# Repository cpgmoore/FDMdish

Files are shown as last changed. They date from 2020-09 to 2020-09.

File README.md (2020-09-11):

# FDMdish
A 3D printable parabolic dish antenna, written in OpenSCAD, with examples rendered for immediate print.

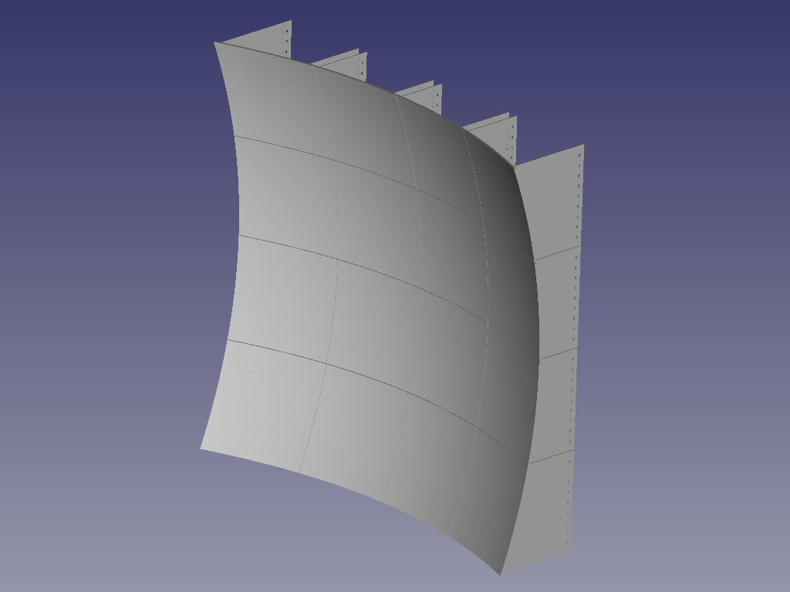
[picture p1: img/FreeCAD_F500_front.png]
|  |
|:-:|
| Included example render: 200mm tiles, 800x800mm dish size, focal distance 500mm |

FDMdish is a 3D printable, scalable parabolic reflector surface system suitable for use in a high gain radio antenna setup.
The parametric model is generated in OpenSCAD, STLs can be rendered/exported and used to generate tiles that can be 3D printed. The accompanying Cura slicer settings have been optimised for high speed printing, using a low volume of material for high paraboloid surface accuracy up to ~10Ghz (maybe 20GHz, requires testing).

The tiles are mounted to a frame of 2020 aluminium extrusion.
Use some currently unknown method to place the RF antenna feed at the focal point.

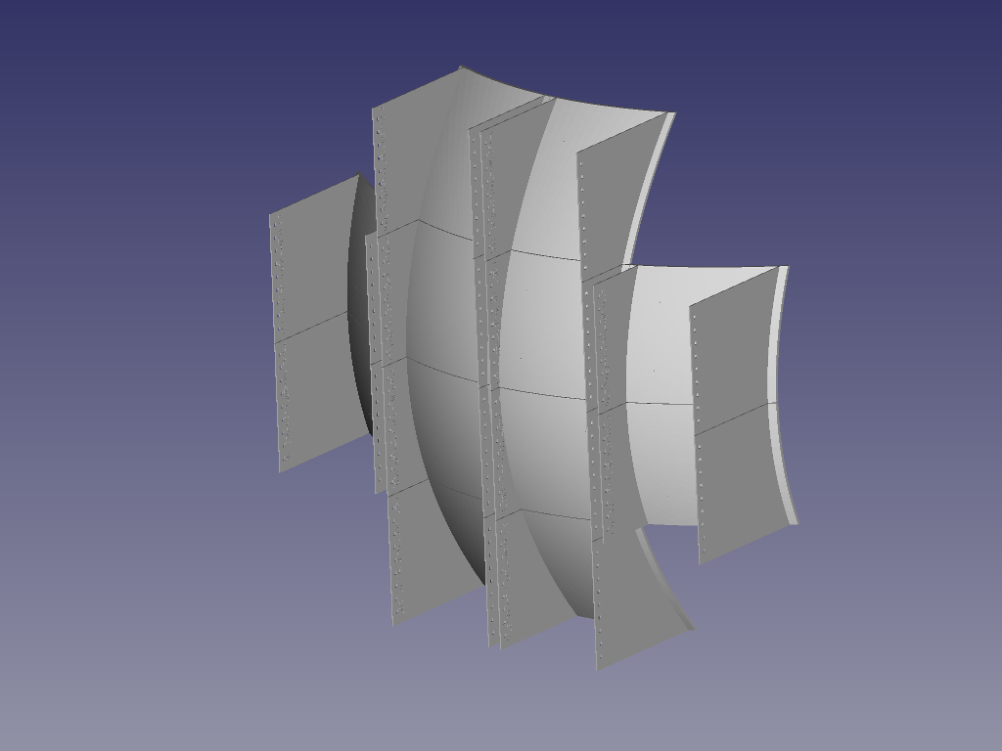
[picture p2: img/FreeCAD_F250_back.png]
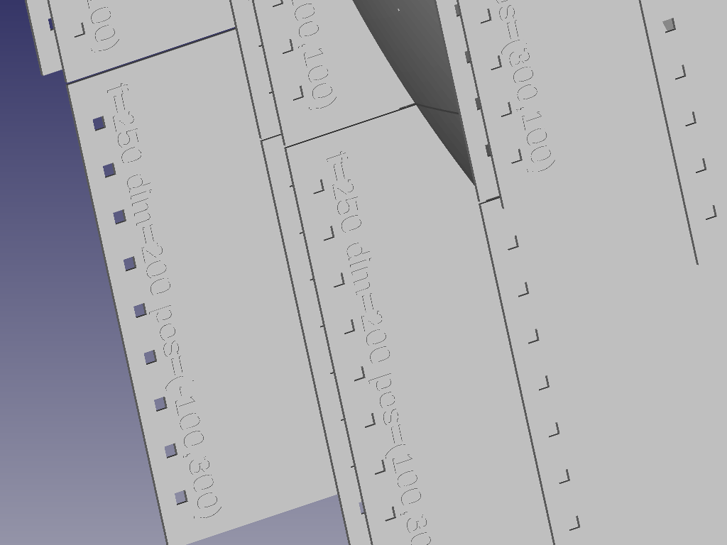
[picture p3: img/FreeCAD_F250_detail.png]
|   |   |
|:-:|:-:|
| Rear view, showing supports | Tiles are labeled |

## Ingredients:
* Ideal 3D printer: Artillery Sidewinder X1, with a 0.8mm nozzle for 1mm line width and 0.5mm layer height. Or equivalent machine
* A few KG of PLA filament, the slicer will tell you how much you need, white is less likely to melt in the sun than black
* Lengths of 2020 vslot extrusion or square hollow section, other widths are possible if you modify the OpenSCAD script
* Brackets to hold the 2020 extrusion in a sturdy frame (see images for examples)
* M5 (ideal), M4 or M3 fasteners and slot nuts
* Beers and patience
* Conductive tape, or conductive nickel spray paint for the reflector surface

## Method:
* Specific custom tiles can be generated by adjusting the parameters in the OpenSCAD script
* Whole dish assemblies can be batch rendered by modifying the parameters in the shell script, and running it (gen_dish.sh)
* The rendered STL files will be stored in the ./render folder
* Check the whole render job, but importing the STLs into a new FreeCAD project
* Load each of these files into your slicer of choice (an optimised profile for CURA and the Sidewinder X1 has been included for tips)
* The 3D printer and slicer should be set up for printing of dimensionally accurate functional components, otherwise there may be a few tight fits
* Print each tile out, trimming the brim
* Once printed, the tiles can be fastened to a grid of 2020 extrusion
* Get creative with ensuring the surface of the dish is electrically conductive, at least in the direction of polarisation, examples include:
 * Copper tape, spaced less than 1/10 wavelength apart
 * Conductive nickel spray paint
 * AluminIum foil and adhesive
 * Thin wire, taped down, ghetto pride

### Hints on SCAD tweaking:
* A high speed, thick layer height print process is unlikely to be tolerant of anything more than a 45deg overhang
 * So the on-axis diameter should be less than 4 times the focal length
* For a square dish at this critical limit, the corners are likely to exceed this requirement and may need to be discarded

### Hints on slicer settings:
* The SCAD model and slicer settings have been optimised for each other, the outcome may be less than ideal with a narrower nozzle
* The structural strength comes from the aluminium extrusion, these panels are designed to be rigid and low warp, but not load bearing
* 1 shell wall, fill of approximately 5-10% with a zigzag pattern seems to provide enough strength to prevent warping in the paraboloid as it cools
* Black gloss filament is good as a prototyping filament, because the quality of the surface can be quickly observed by looking for variations in the reflective sheen as the tile is rotated under a point source of illumination 
* printing with a brim is essential (these components are large, with a low bed contact area, and are otherwise likely to lift off the bed)

### Hints on printing:
* Approximate time per tile with the described setup: 2-3 hours

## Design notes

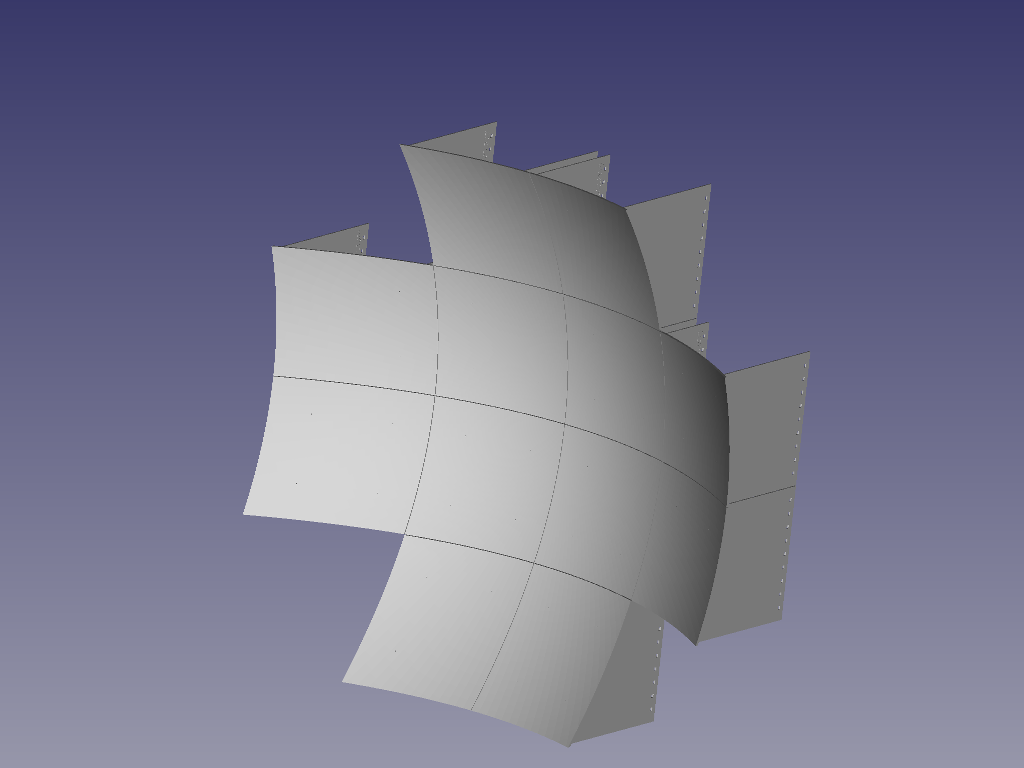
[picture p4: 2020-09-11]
img/FreeCAD_F250_front.png

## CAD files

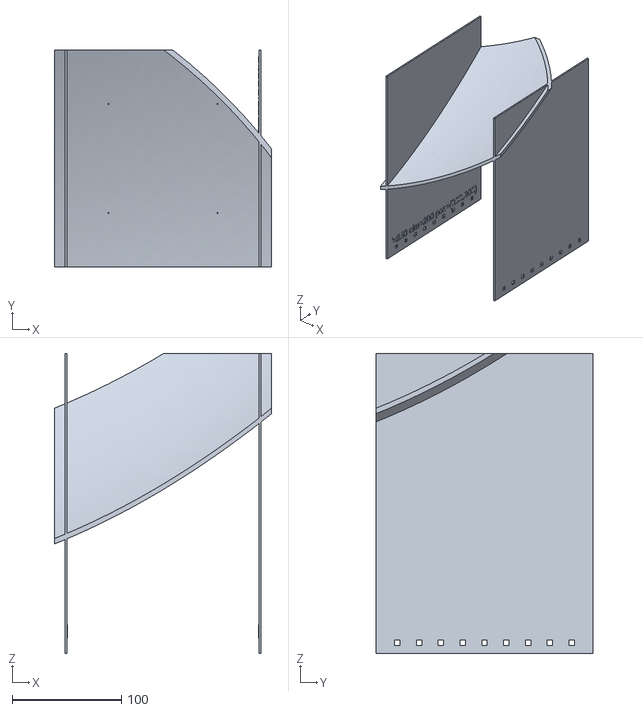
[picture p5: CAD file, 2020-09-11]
render/dish_F250_tile_200_+300_+300.stl
199.0 x 199.0 x 275.0

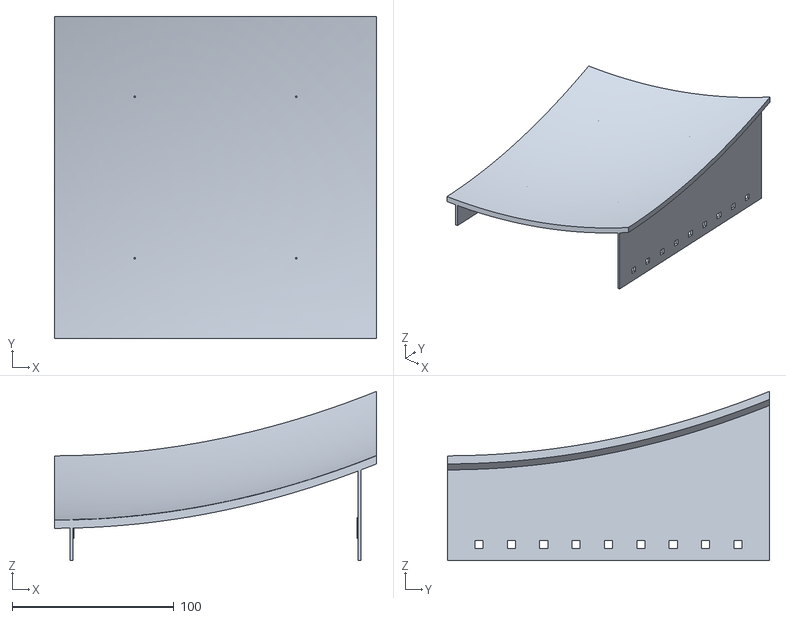
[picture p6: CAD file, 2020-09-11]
render/dish_F250_tile_200_+100_+100.stl
199.0 x 199.0 x 104.6

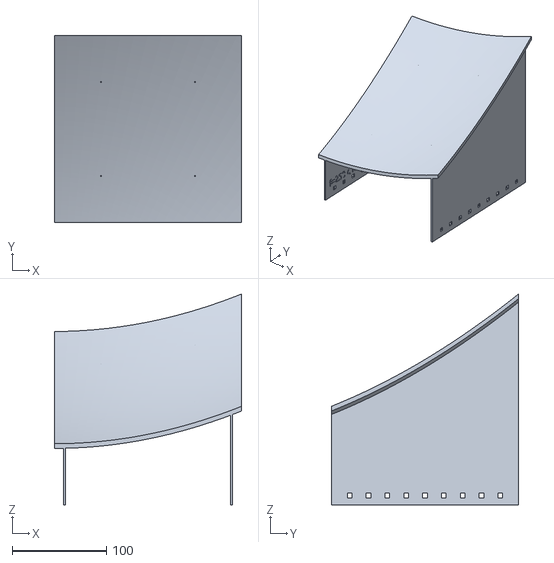
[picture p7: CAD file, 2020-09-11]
render/dish_F250_tile_200_+100_+300.stl
199.0 x 199.0 x 224.5

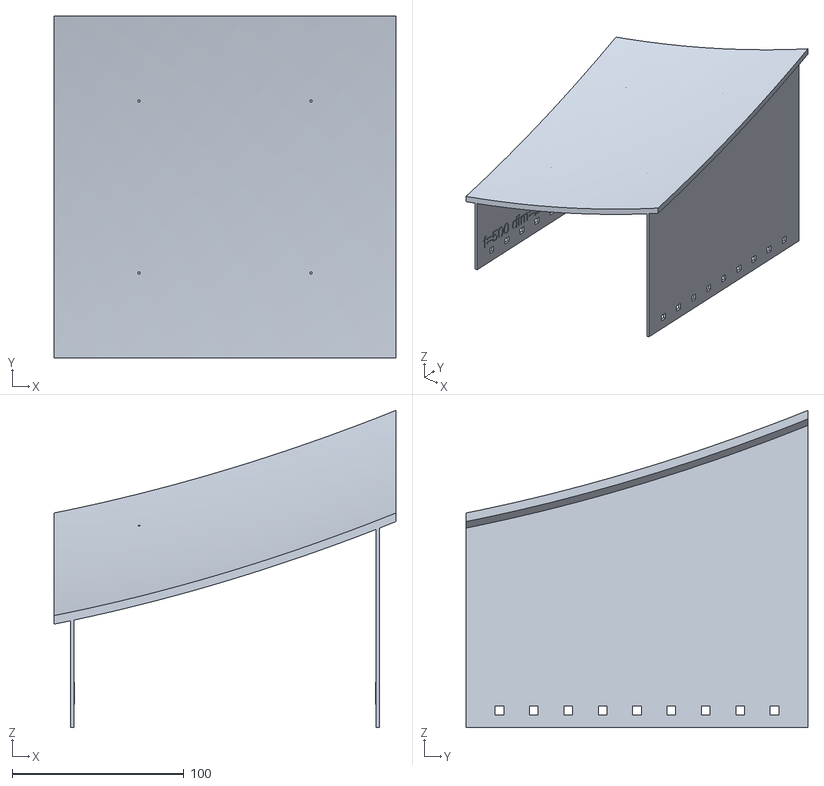
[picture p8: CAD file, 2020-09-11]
render/dish_F500_tile_200_+300_+300.stl
199.0 x 199.0 x 184.7

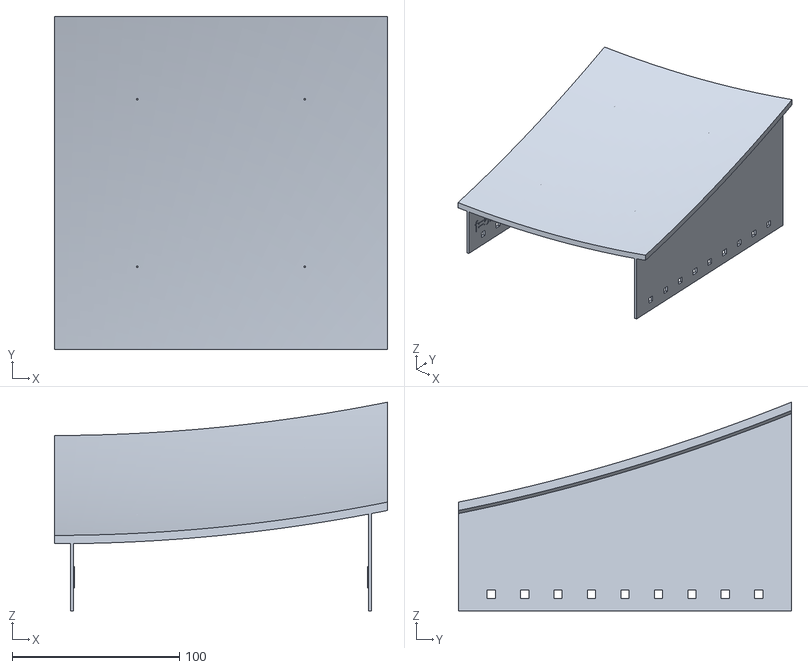
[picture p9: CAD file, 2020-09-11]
render/dish_F500_tile_200_+100_+300.stl
199.0 x 199.0 x 124.7

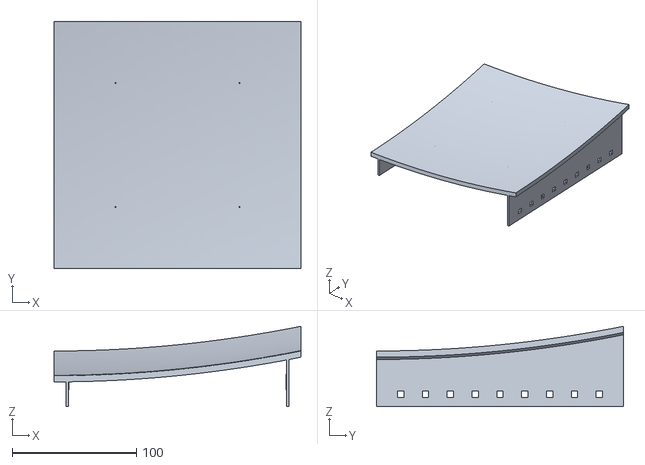
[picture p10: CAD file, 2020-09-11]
render/dish_F500_tile_200_+100_+100.stl
199.0 x 199.0 x 64.8

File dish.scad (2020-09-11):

//Auth  CPGMoore
//Src   http://www.github.com/cpgmoore/FDMdish
//Lic	MIT

/* Hints:
Typical print volumes for low cost 3d printers are in the order of 200^3 to 300^3
The tiles here are dimensioned to fill the max build volume of the available printer
Expected extrusion width is 1mm (0.8mm nozzle)
Material must be low warp, PLA/PETG are ideal candidates
Typical overhang limits for agressive layer heights are to not exceed 45deg
This limit is met when the focal length is approximately equiv. to half the total assembled panel width
eg: 
    2 panels wide, 200mm/panel = 400mm wide, focal length should be 200mm
    4 panels wide, 200mm/panel = 800mm wide, focal length should be 400mm
    2 panels wide, 300mm/panel = 600mm wide, focal length should be 300mm
    4 panels wide, 300mm/panel = 1200mm wide, focal length should be 600mm
*/


/* [Paraboloid] */
show_paraboloid=false;
show_focal_point=false;
paraboloid_focal_length_mm=250;
paraboloid_surface_thickness_mm=5.0;

/* [Supports] */
show_plane=false;
//This is the depth below the XY plane, with a surface thickness of 5mm, 25mm gives 20mm of clearance behind the paraboloid volume
plane_offset_z_mm=-25;
//CAUTION: experimental feature, adjusts the support plane to allow for a greater range of off axis arrangements
plane_rotate_x_deg=0;
show_supports = false;
//Ideally twice the 3D print process line width
support_thickness_mm=2;
paraboloid_limit_z_mm=400;

//A distance of 10mm between the internal support surface and the ideal edge of a tile, allows 20x20mm extrustion as a rigid support between tiles
support_edge_offset_mm=10;
//Support holes allow the tile to be bolted to the extrusion support beam, square holes are computationally cheaper
support_holes_mm = 5.0;


//the tile is located in the XY plane,
//Then the plane is rotated
//Rotation of the plane is somewhat experimental
//And is intended for off axis reflectors of angles approx ~ 90deg
//The angle should be experimented with the produce parts that can be reliably printed by the FDM process
/* [Printable Tile] */
show_tile_mask = false;
show_tile_masked_shell=true;
show_tile_masked_support=true;
tile_dim_mm=200;
tile_location_x=100.0;
tile_location_y=100.0;
tile_edge_clearance_mm=1.0;
//Alignment guides provide a reference point for locating mirrors at regular intervals. This would allow fine tuning of mounted positions for better focus.
enable_alignment_guides = true;
show_alignment_guides = false;
alignment_guide_dim_mm=1.0; //



//A paraboloid is defined as following the equation:
// y = x^2/(4*focal length)


//The following allows us to constrain construction of the paraboloid for improved efficiency, using worst case orientation of tile
//These functions are not rigourously derived rocket science, and contain some additional fudging and safety factors
tile_center_to_vertex=tile_dim_mm/2.0*sqrt(2);
paraboloid_radius_max_mm=round(sqrt(pow(tile_location_x,2)+pow(tile_location_y,2))+tile_center_to_vertex) + 200; //+200 to fudge in the experimental features
//paraboloid_radius_min_mm=sqrt(pow(tile_location_x,2)+pow(tile_location_y,2))-tile_center_to_vertex;
//paraboloid_radius_max_mm=500;

module 2D_paraboloid_shell_slice(focal_length,radius, thickness_offset_y, N_segments){
	//http://forum.openscad.org/2dgraph-equation-based-2-D-shapes-in-openSCAD-td15722.html
    interval=radius/N_segments;
    //more complicated than it needs to be, but avoids problems with floating points and thin shells
    x_set_for=[for(x = [0:interval:radius]) x ];
    x_set_rev=[for(i = [len(x_set_for)-1:-1:0]) x_set_for[i]];
    
	polygon(points=concat(
        //reference surface, starting centre
        [for(x=x_set_for)
            [x,(x*x)/(4*focal_length)]	],
        //Offset surface, starting at edge
        [for(x=x_set_rev)
            [x,(x*x)/(4*focal_length)+thickness_offset_y]	]
	));
}
//2D_paraboloid_shell_slice(250,250,-5,10);

module 3D_paraboloid_shell(focal_length,radius, thickness_z){
	rotate_segment_angle_deg=2;

    rotate_extrude(angle=360, convexity=1,$fa=rotate_segment_angle_deg){
        segment_length_mm=5.0;
        
        N_segments=ceil(radius/segment_length_mm);
        2D_paraboloid_shell_slice(focal_length,radius,thickness_z,N_segments);
    }
}
//3D_paraboloid_shell(250,500,5);

module 2D_paraboloid_slice(focal_length,radius,limit_y,N_segments){
	//http://forum.openscad.org/2dgraph-equation-based-2-D-shapes-in-openSCAD-td15722.html
    interval=radius/N_segments;
    //interval=10;
	polygon(points=concat(
                            //Paraboloid surface, starting centre
                            [for(x=[0:interval:radius])
                                [x,(x*x)/(4*focal_length)]	],
                            //Take it to the limit, then back to the center at the limit
                            [[radius,limit_y], [0,limit_y]]
	));
}
//2D_paraboloid_slice(100,100,1000,10);

module 3D_paraboloid(focal_length, radius, limit_z){
	rotate_segment_angle_deg=2;
    
    rotate_extrude(angle=360, convexity=1,$fa=rotate_segment_angle_deg){
        segment_length_mm=5.0;
        
        N_segments=ceil(radius/segment_length_mm);
        2D_paraboloid_slice(focal_length,radius,limit_z, N_segments);
    }
}
//3D_paraboloid(250,500,1000);


//******************************************************************************



module shell(){
    3D_paraboloid_shell(paraboloid_focal_length_mm, paraboloid_radius_max_mm,-paraboloid_surface_thickness_mm);

}



//******************************************************************************



module fastener_negative(wall_thickness){
    translate([0,0,10]){
        //A cube is cheaper than a cylinder, and functionally the same result for a cylindrical fastener
        cube(size=[wall_thickness,support_holes_mm,support_holes_mm],center=true); 
    }
}
//fastener_M3_negative(10);

module single_support(){
    difference(){
        
        wall_depth=paraboloid_limit_z_mm-plane_offset_z_mm;
        wall_offset=wall_depth/2+plane_offset_z_mm;
        
        
        //translate([0,0,wall_offset]){
        difference(){
            translate([0,0,wall_depth/2]){
                cube(size=[support_thickness_mm,tile_dim_mm,wall_depth],center=true);
            }
            
            for(y=[-80:20:+80]){
                translate([0,y,0]){
                    fastener_negative(support_thickness_mm+1);
                }
            }
        }
    }
}
//single_support();

module label_params(){

    text_size=10;
    translate([0,10,0]){
        text(str("f=", paraboloid_focal_length_mm, " dim=",tile_dim_mm," pos=(", tile_location_x,",", tile_location_y,")"),halign="center",valign="center",size=text_size);
    }
}

module label_source(){

    text_size=10;
    translate([0,10,0]){
        //alternatives: FDMdish print-a-dish
        text("github.com/cpgmoore/FDMdish",halign="center",valign="center",size=text_size);
    }
}

module label_support_params(){
    translate([support_thickness_mm/2-0.5,0,10]){
        rotate(a = 90, v=[0, 1, 0]){
            rotate(a = 90, v=[0, 0, 1]){
                linear_extrude(height = 1.0){
                    label_params();
                }           
            }
        }
    }
}
// support_label();

module label_support_source(){
    translate([-support_thickness_mm/2+0.5,0,10]){
        rotate(a = -90, v=[0, 1, 0]){
            rotate(a = -90, v=[0, 0, 1]){
                linear_extrude(height = 1.0){
                    label_source();
                }           
            }
        }
    }
}

module supports(){  
    tile_edge=tile_dim_mm/2;
    support_center_offset=tile_edge-support_edge_offset_mm-support_thickness_mm/2;
    translate([-support_center_offset,0,0]){
        single_support();
        label_support_params();
    }
    
    translate([support_center_offset,0,0]){
        single_support();
        label_support_source();
    }
}
//supports();

module support_tile(){
    difference(){
        rotate(a=plane_rotate_x_deg, v=[1,0,0]){
            translate([tile_location_x,tile_location_y,plane_offset_z_mm]){
                supports();
            }
        }
        3D_paraboloid(paraboloid_focal_length_mm, paraboloid_radius_max_mm, 2*paraboloid_focal_length_mm);
    }
}


//******************************************************************************


module focal_point(){
    translate([0,0,paraboloid_focal_length_mm]){
        sphere(10);
    }
}

module plane(){
    rotate(a=plane_rotate_x_deg,v=[1,0,0]){
        translate([0,0,plane_offset_z_mm-1]){
            cube(size=[2000,2000,1], center=true);
        }
    }
}

module alignment_guides(){
    
    offset=tile_dim_mm/4;
    height=500;
    for(x=[-offset,+offset]){
        for(y=[-offset,+offset]){
            translate([tile_location_x+x,tile_location_y+y,0]){
                    cube(size=[alignment_guide_dim_mm,alignment_guide_dim_mm,height],center=true);
            }
        }
    }
}
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

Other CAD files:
render/dish_F500_tile_200_+300_+100.stl
render/dish_F250_tile_200_+300_+100.stl
render/dish_F250_tile_200_+100_-100.stl
render/dish_F250_tile_200_+100_-300.stl
render/dish_F250_tile_200_+300_-100.stl
render/dish_F250_tile_200_+300_-300.stl
render/dish_F250_tile_200_-100_+100.stl
render/dish_F250_tile_200_-100_+300.stl
render/dish_F250_tile_200_-100_-100.stl
render/dish_F250_tile_200_-100_-300.stl
render/dish_F250_tile_200_-300_+100.stl
render/dish_F250_tile_200_-300_+300.stl
render/dish_F250_tile_200_-300_-100.stl
render/dish_F250_tile_200_-300_-300.stl
render/dish_F500_tile_200_+100_-100.stl
render/dish_F500_tile_200_+100_-300.stl
render/dish_F500_tile_200_+300_-100.stl
render/dish_F500_tile_200_+300_-300.stl
render/dish_F500_tile_200_-100_+100.stl
render/dish_F500_tile_200_-100_+300.stl
render/dish_F500_tile_200_-100_-100.stl
render/dish_F500_tile_200_-100_-300.stl
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

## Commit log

2020-09-11 Added renders
    [dish_F250_tile_200_+100_+100.stl, dish_F250_tile_200_+100_+300.stl, dish_F250_tile_200_+100_-100.stl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]
2020-09-11 Added first notes to README, added optimised slicer profile for 3D printer
